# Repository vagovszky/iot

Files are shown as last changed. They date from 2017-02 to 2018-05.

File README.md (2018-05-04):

# IoT project
IoT project with usage of ESP8266 - [Wiki page](https://github.com/vagovszky/iot/wiki)

## Roadmapa - sketch

### Hardware - Hlavní modul

- [X] Návrh HW - schema (únor 2017)
- [X] Návrh HW - DPS (únor 2017)
- [X] Výroba DPS - Prototyp (únor 2017)
- [X] Osazení DPS (brezen 2017)
- [X] Celková kompletace modulu (brezen 2017)
- [X] Základní otestování (brezen 2017)

### Hardware - Přídavné moduly

- [X] Modul čidlo teploty
- [X] Modul I/O

## Výsledná sestava

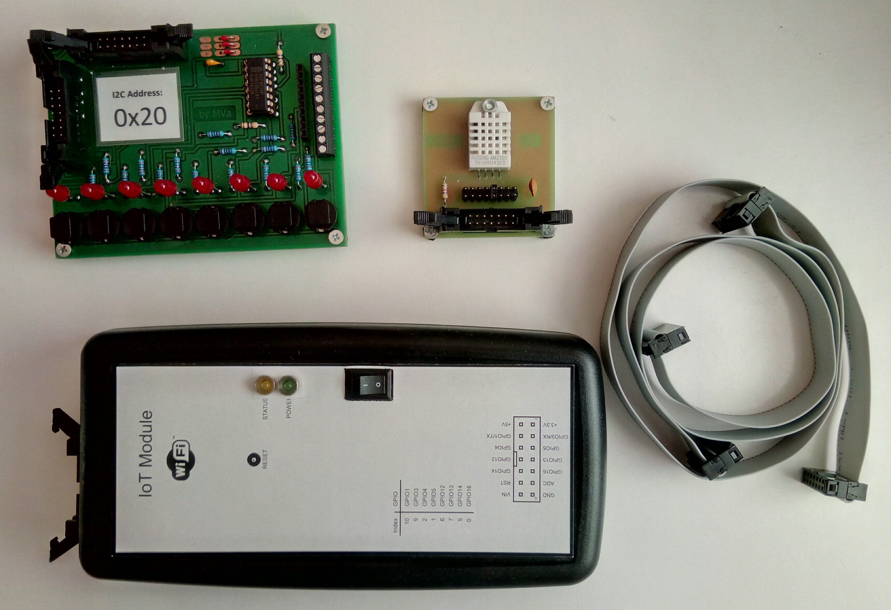
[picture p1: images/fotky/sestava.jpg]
Sestava


## Screenshot z webové aplikace k ovládání modulu

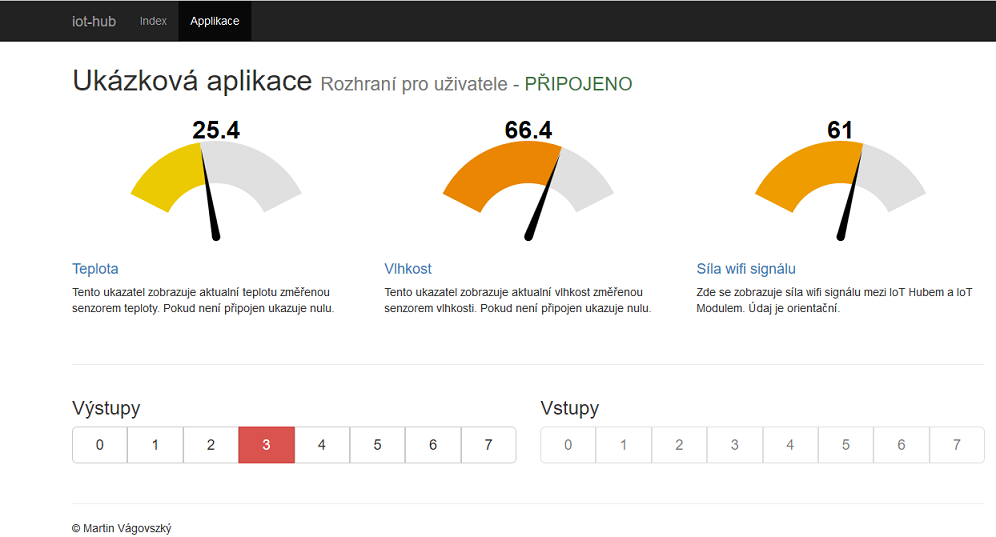
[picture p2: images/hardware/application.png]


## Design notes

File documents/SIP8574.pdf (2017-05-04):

# 8 I/O Port with LEDs and Relay

## September 29, 2009

## Contents

1 Introduction | 2
2 I2C Communications | 2
3 Operation | 2
4 Relay | 3
5 Misc Modifications | 4
6 Jumpers | 5
7 Edge Connector | 5
8 Drawings | 5
9 I2C Keyboard Drawings | 7
10 Revision History | 9

1

8 I/O Port with LEDs and Relay

## 1 Introduction

SIP8574 is a simple 8 bit I/O port module using the NXP (http://www.nxp.com) PCF8574 (http://www.nxp.com/pip/PCF8574_4.html)

This is the simplest I/O chip for I2C, with no input, output or data direction registers to configure. It has open drain outputs, which can be written or read.

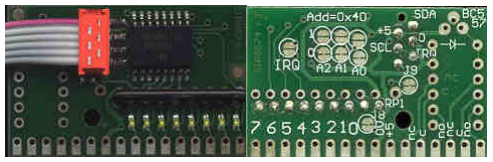
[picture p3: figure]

- 8 Open Drain I/O’s, 20mA
- Interrupt on pin change output
- TI 2nd source available

The SIP8574 module is included in the I2C Starter Kit.

I2C Keyboard

I2CKBD is a simple 8 buttons+leds pcb using the 8574.

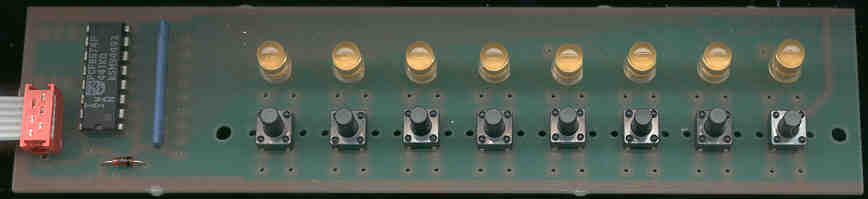
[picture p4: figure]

## 2 I2C Communications

The base address if PCF8574 is 0x40. 8 sub-addresses are available through J1-6.

There are no internal registers, all reads and write are direct to/from the port.

## 3 Operation

### 3.1 Input

Any pin you want to use as an input should be set HI.

S40 FF P //set all pins to be inputs

S41 01 P //read the input value

©Broadcast Equipment Ltd 2009 | www.i2cchip.com | SIP8574.lyx pg 2 of 9

8 I/O Port with LEDs and Relay

### 3.2 Output

The LED’s are ON when the outputs are LOW. So 00 will turn all LED’s on, FF will turn them off.

S40 00 P //all leds on
S40 FF P //all leds off
S40 FE P //relay only ON

You can write sequential bytes to the port to toggle the pins.

S40 FE FF FE FF P //toggle P0 twice

### 3.3 Paralleling Boards on Same Address

You might want to have a couple of boards in different spots, but you are only using a few pins. It might suit you to only have to write to a single location for both boards

You can actually parallel two boards without changing the address is you want. Just use different pins on each board, and leave the unused pins on each board open. This is possible because the I2C bus is open drain.

### 3.4 Reading Keyboards Switches

The I2CKBD has LED’s and buttons connected together.

To read the buttons the outputs are changed to all off - FF, then the port is read, then the LED state is restored.

So if LED state is F0, we can read the inputs, and set the leds like this:

S40 FF R01 W F0 P

ie Write FF, read 1 byte button values, write FF (led state).

### 3.5 Interrupt Pin

The IRQ pin is not connected by default. Bridge J7/IRQ to connect it to the bus.

## 4 Relay

You can order with a DPDT relay fitted. The PCB is labelled

- C - common
- NO - normally open
- NC normally closed.
©Broadcast Equipment Ltd 2009 | www.i2cchip.com | SIP8574.lyx pg 3 of 9

8 I/O Port with LEDs and Relay

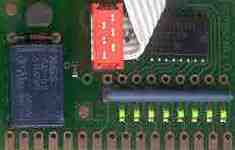
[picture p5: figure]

### 4.1 Relay Specifications

Spec | Value | Units
Type | NAIS TQ2-5V, DPDT
Max Voltage | 110 DC / 125 AC | V
Max Current | 1A | A
Nominal Switching | 30V 1A DC / 125VAC, 0.5A
Coil Current | 28 | mA

### 4.2 Adding the Relay

If not fitted you can add the relay yourself. You require:

- NAIS TQ2 type relay, 5V or equivalent,
- BC557 PNP 100mA transistor
- 1N4148, 1N914 or equivalent signal diode

### 4.3 Changing the Relay Port

By default the relay is connected to P0. To control it with another port, cut link J9. Use a wire to link the pad adjacent to R4, to the desired pad of RP2

[ADD photo]

### 4.4 Using the Relay Driver Without a Relay

The relay is high side driven by a PNP transistor. If you need a high current output, then you can fit Q1. Link across the relay pins to get the signal to the edge connector.

If you are driving an inductive load (eg external relay) be sure to fit D1.

## 5 Misc Modifications

### 5.1 Disable LED’s

To disable the LED’s cut J8.

You might want to do this to reduce current consumption, or if you want to drive the input from a source than cannot turn the LED on.

©Broadcast Equipment Ltd 2009 | www.i2cchip.com | SIP8574.lyx pg 4 of 9

8 I/O Port with LEDs and Relay

### 5.2 Adding Extra Pullup Resistors

The PCF8574 has built in weak pullups. If you want to increase the pullup current, fit RP2.

## 6 Jumpers

J# | Function | default
J1-6 | I2C Sub Address | joined to 0
J7 | IRQ | open
J8 | Cut to disable LED’s | closed
J9 | Cut to change Relay Port | closed

## 7 Edge Connector

Pin | Function
1 | normally open 1
2 | normally closed 1
3 | common 1
4 | normally open 2
5 | normally closed 2
6 | common 2
7 | +5
8 | GND
9 | IO 0
10 | IO 1
11 | IO 2
12 | IO 3
13 | IO 4
14 | IO 5
15 | IO 6
16 | IO 7

## 8 Drawings

### 8.1 Circuit Diagram

©Broadcast Equipment Ltd 2009 | www.i2cchip.com | SIP8574.lyx pg 5 of 9

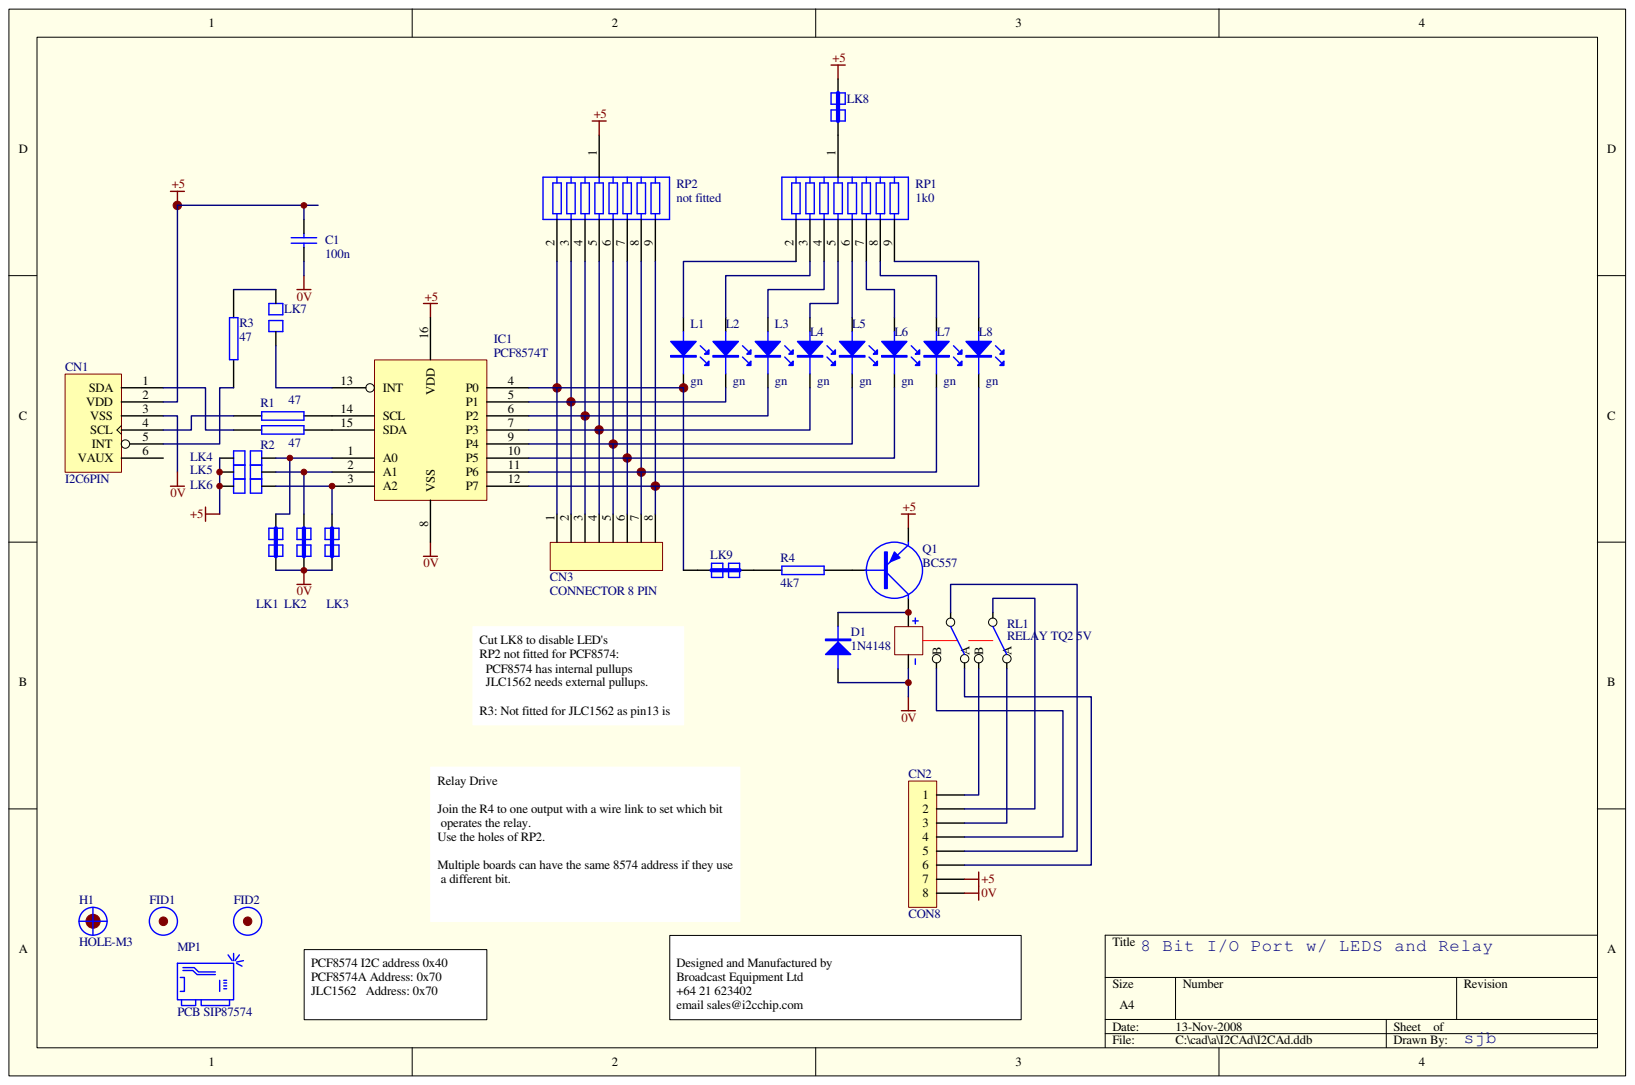
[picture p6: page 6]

Cut LK8 to disable LED's
RP2 not fitted for PCF8574:
PCF8574 has internal pullups
JLC1562 needs external pullups.

R3: Not fitted for JLC1562 as pin13 is

Join the R4 to one output with a wire link to set which bit
operates the relay.
Use the holes of RP2.

Multiple boards can have the same 8574 address if they use
a different bit.

Title
8 Bit I/O Port w/ LEDS and Relay

Designed and Manufactured by
Broadcast Equipment Ltd
email sales@i2cchip.com

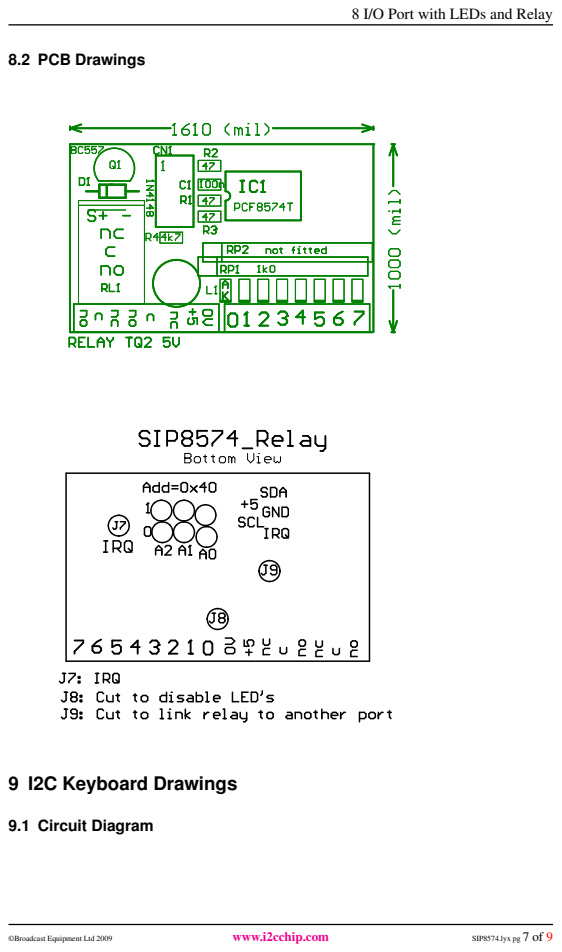
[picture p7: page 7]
8.2 PCB Drawings; 9 I2C Keyboard Drawings; 9.1 Circuit Diagram; ©Broadcast Equipment Ltd 2009; www.i2cchip.com; SIP8574.lyx pg 7 of 9

8 I/O Port with LEDs and Relay

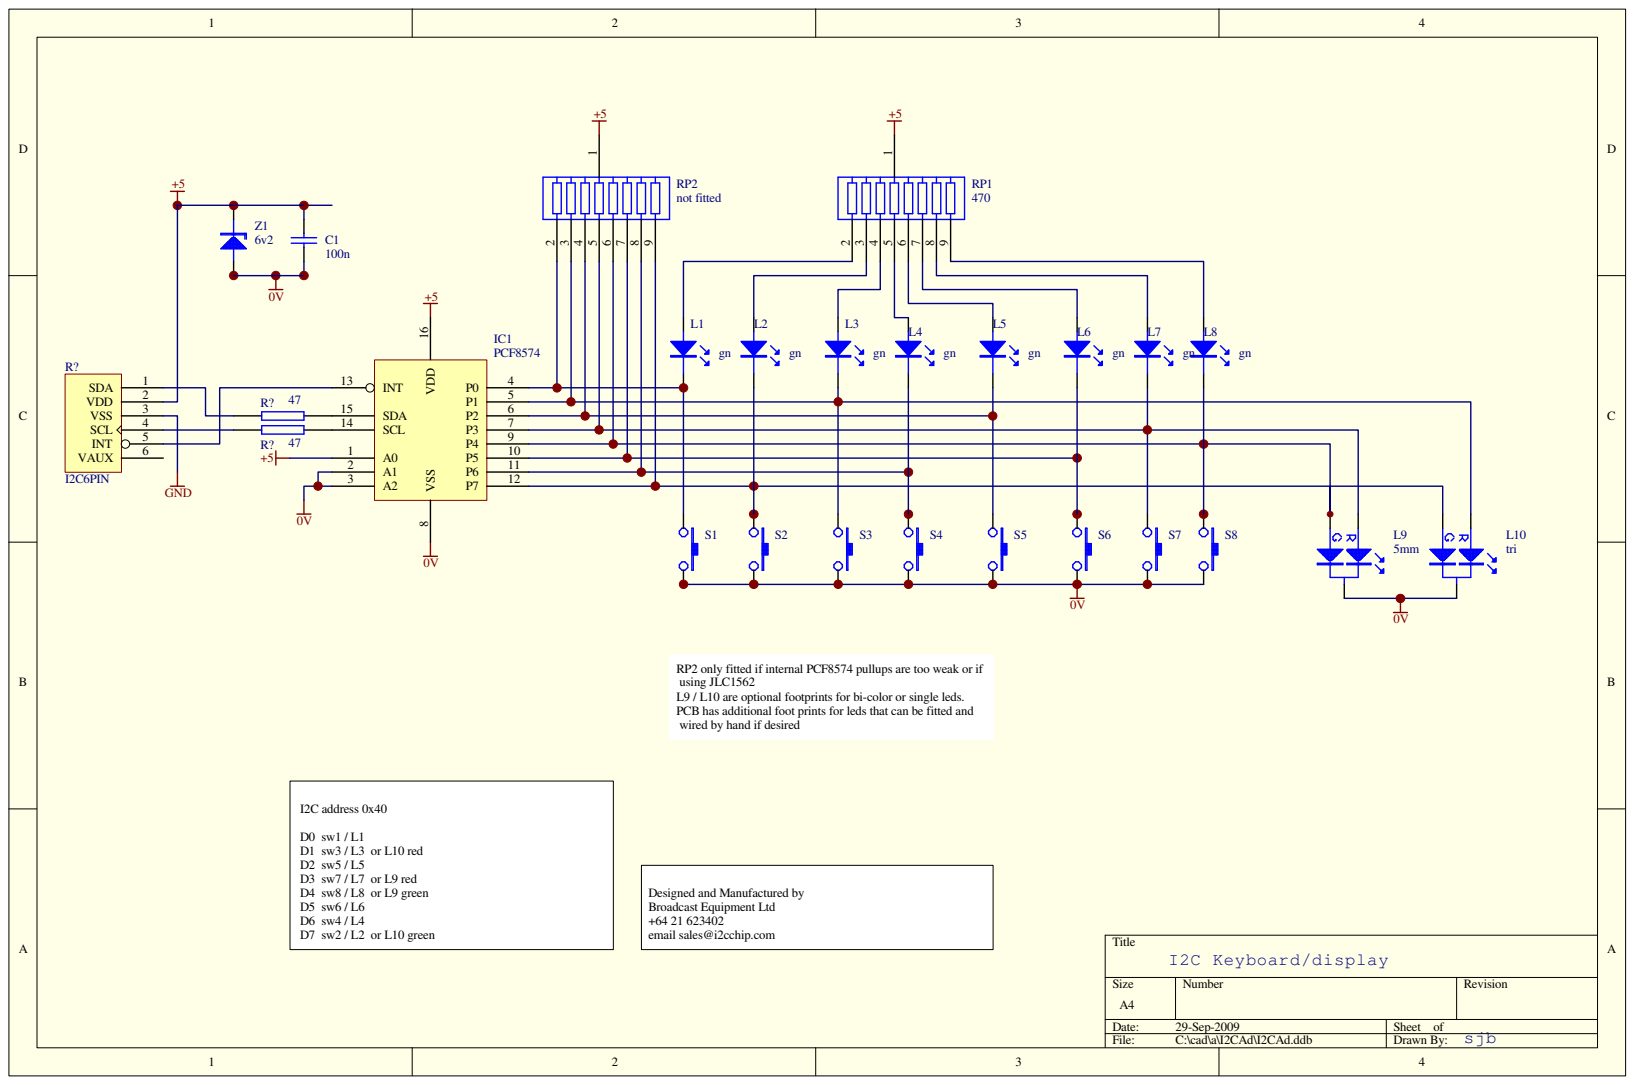
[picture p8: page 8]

RP2 only fitted if internal PCF8574 pullups are too weak or if
using JLC1562
L9 / L10 are optional footprints for bi-color or single leds.
PCB has additional foot prints for leds that can be fitted and
wired by hand if desired

Designed and Manufactured by
Broadcast Equipment Ltd
email sales@i2cchip.com

8 I/O Port with LEDs and Relay

## 10 Revision History

Date | Rev# | Changes
| 0 | pre-release
©Broadcast Equipment Ltd 2009 | www.i2cchip.com | SIP8574.lyx pg 9 of 9

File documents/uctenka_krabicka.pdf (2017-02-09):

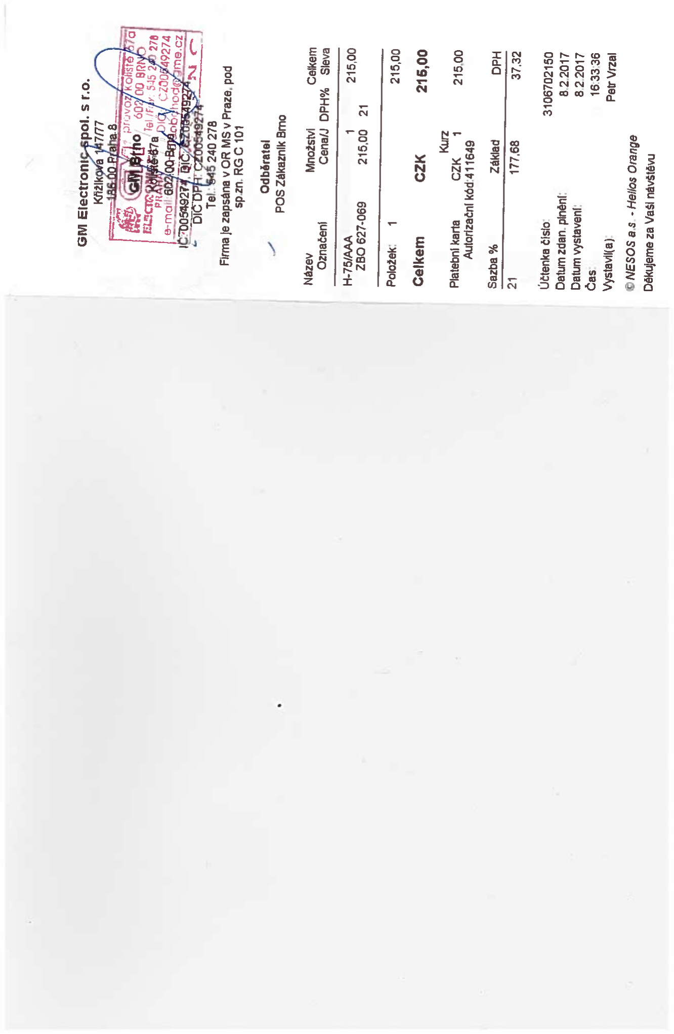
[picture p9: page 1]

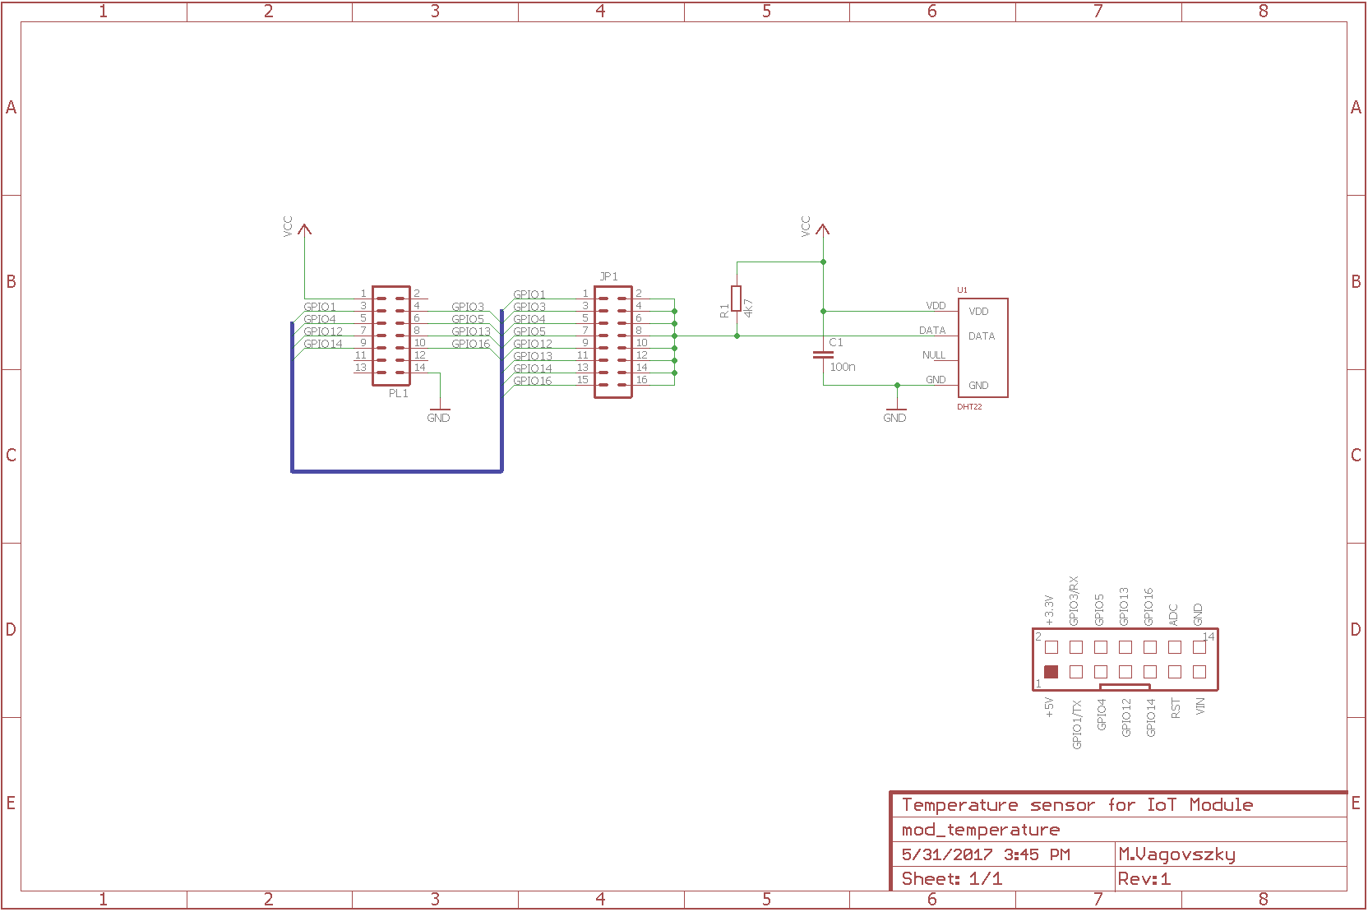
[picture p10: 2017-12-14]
images/hardware/mod_temperature_schema.png

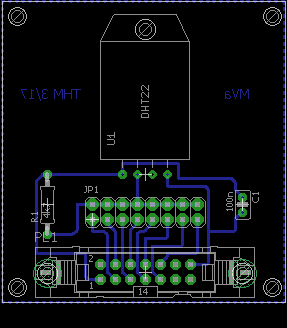
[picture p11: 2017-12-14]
images/hardware/mod_temperature_board.png

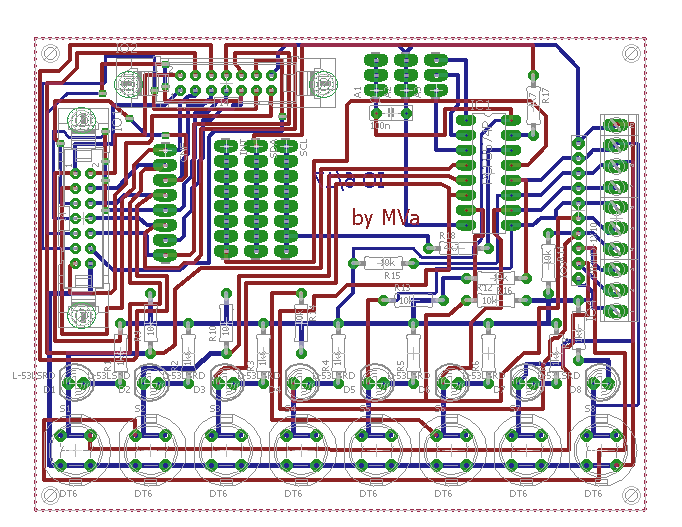
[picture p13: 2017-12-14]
images/hardware/mod_io_board_white.png

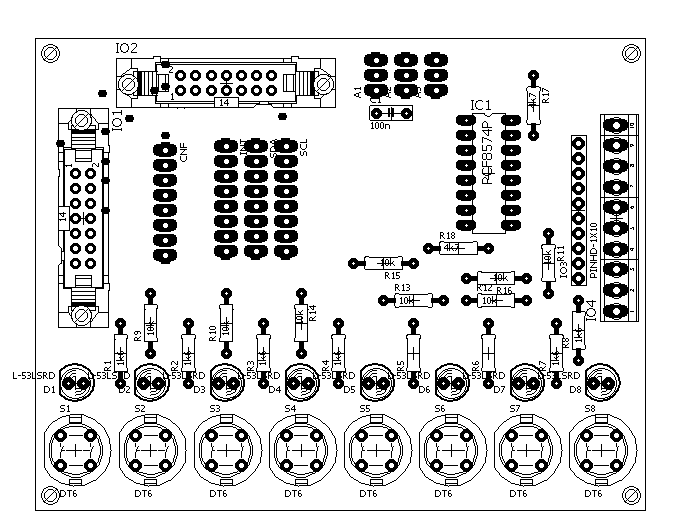
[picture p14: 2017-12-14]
images/hardware/mod_io_osaz.png

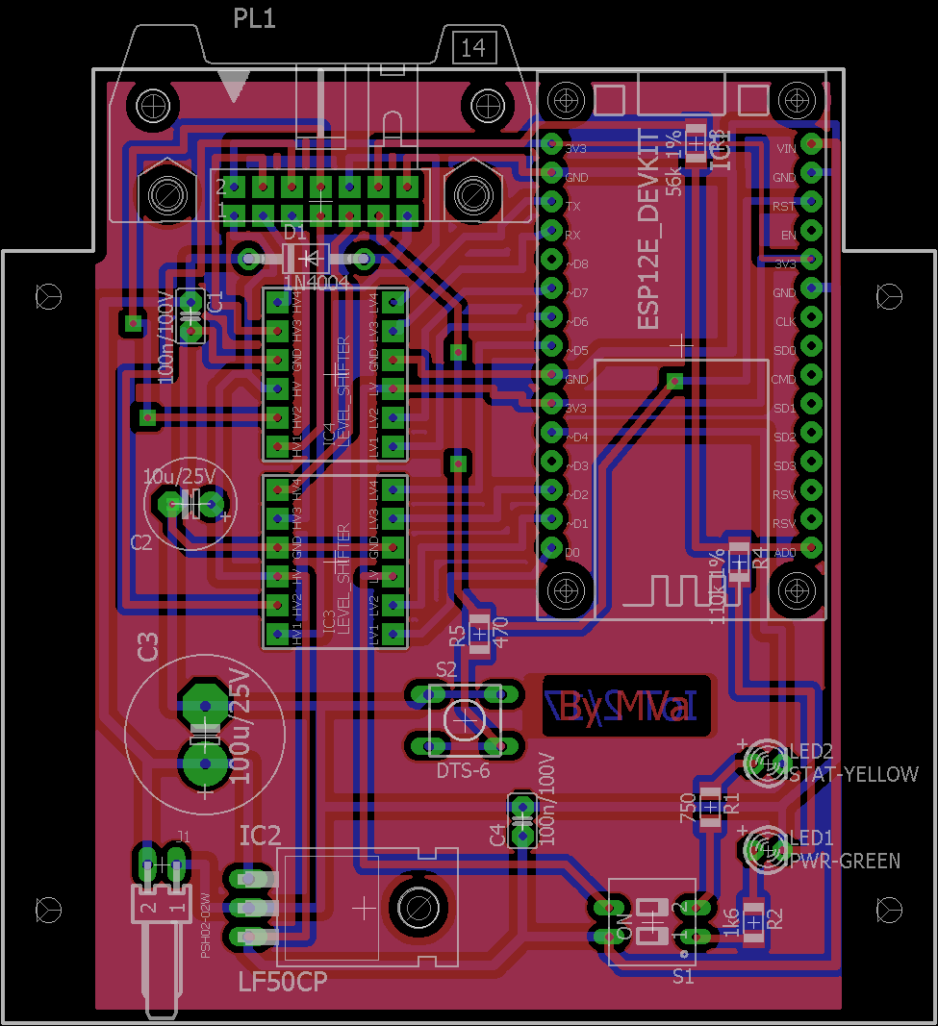
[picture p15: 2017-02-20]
images/hardware/board.png

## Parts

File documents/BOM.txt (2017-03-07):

C1,C4 KONDENZATOR 100n/100V - 2ks                      
C2    KONDENZATOR 10u/25V ELYT - 1ks                  
C3    KONDENZATOR 100u/25V ELYT - 1ks                 
D1    DIODA 1N4004 - 1ks                     
IC1   ESP12E_DEVKIT (EBAY) - 0ks       
IC2   REGULATOR LF50CP TO220H 5V LDO Regulator - 1ks          
IC3   LEVEL_SHIFTER Level shifter 5V <-> 3.3V (EBAY) - 0ks    
IC4   LEVEL_SHIFTER Level shifter 5V <-> 3.3V (EBAY) - 0ks   
J1    KONEKTOR PSH02-02W + OPACNÝ DÍL + PINY - 1ks                
LED1  LED 3MM Green BL-B2141-L (1,8V / 2mA) - 1ks                      
LED2  LED 3MM YELLOW HLMP-1719 (1,8V / 2mA) - 1ks                       
PL1   KONEKTOR PSL14W - 1ks                 
R1    REZISTOR 750 SMD 1206 - 2ks 
R2    REZISTOR 1k6 SMD 1206 - 2ks 
R3    REZISTOR 56k 1% SMD 1206 - 2ks 
R4    REZISTOR 110k 1% SMD 1206 - 2ks 
R5    REZISTOR 470 SMD 1206 - 2ks 
S1    SPÍNAC DO DPS DIP 02 RED/BLACK - 1ks          
S2    MIKROSPINAC DO DPS (asi TC-0111-T 13.5MM) - zmmerit delku hmatniku - 1ks
S3    POSUVNY SPINAC JEDNOPOLOVY CERNY DO PANELU - 1ks

Objímka pro led 3mm do panelu (reflektor / sokl) - 2ks
KONEKTOR PFL14 (NA KABEL) + TRMEN - 4ks
Podložky pod sroub M3 plastove
Distancni sloupek plastovy maly (5mm)

Krabicka H-75/4AA - 0ks
Plochý kabel - 14 žil - 1m

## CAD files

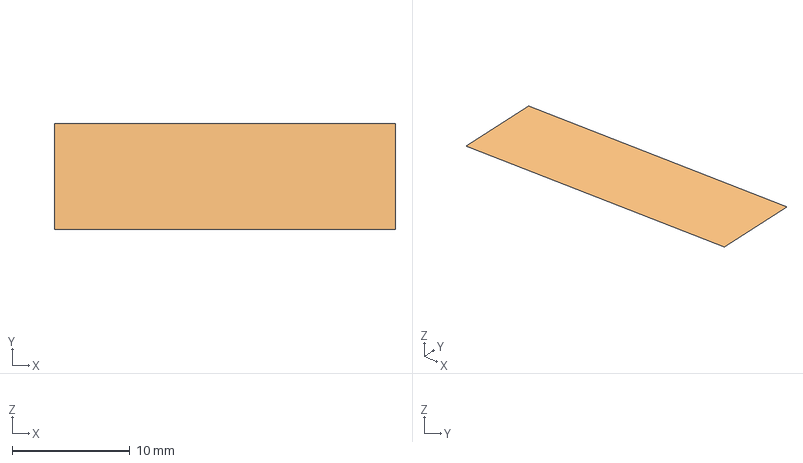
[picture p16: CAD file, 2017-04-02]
freecad/IoT_Front_Label.fcstd
29.0 x 9.00 x 0 mm
Pins
Closure
Locker

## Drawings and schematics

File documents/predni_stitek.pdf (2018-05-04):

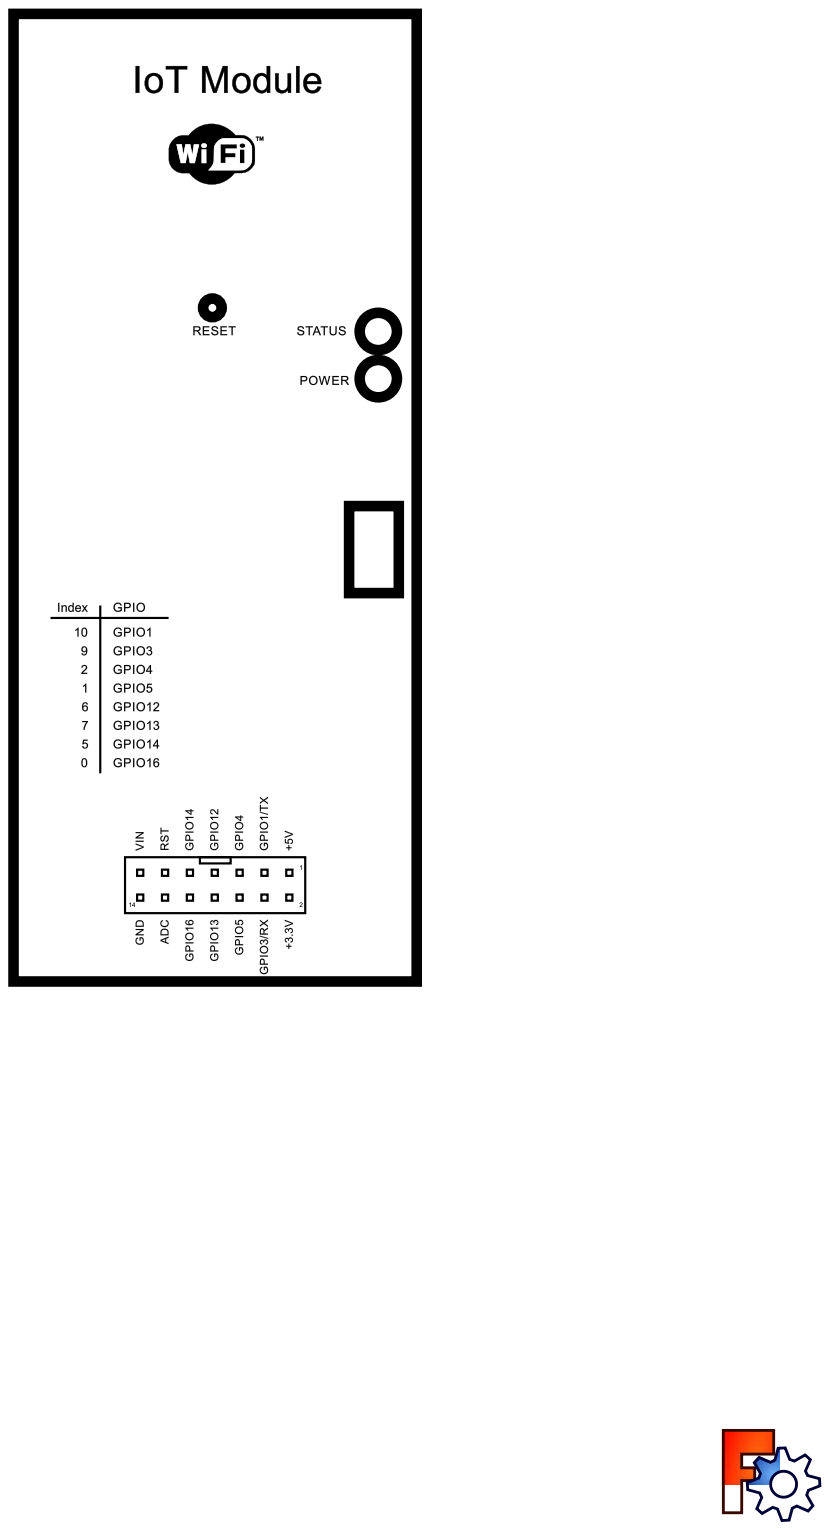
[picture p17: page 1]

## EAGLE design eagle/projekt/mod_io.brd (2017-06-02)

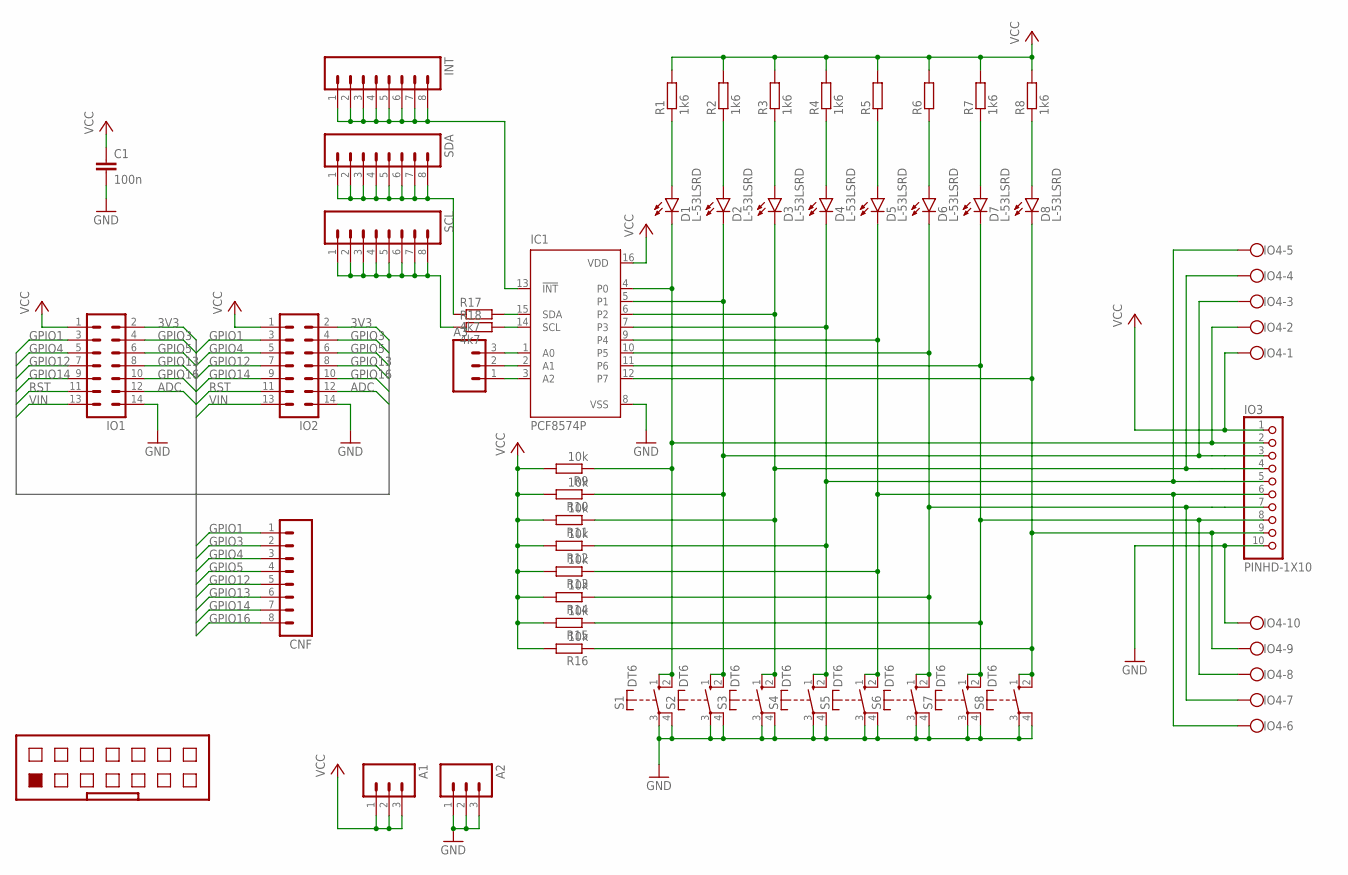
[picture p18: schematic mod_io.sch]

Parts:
A1, A2, A3: M03LONGPADS; 1X03_LONGPADS
C1: 100n; C050-025X075
CNF: M08LONGPADS; 1X08_LONGPADS
D1, D2, D3, D4, D5, D6, D7, D8: L-53LSRD; LED5MM
IC1: PCF8574P; DIL16
INT: M08LONGPADS; 1X08_LONGPADS
IO1, IO2: 14V
IO3: PINHD-1X10; 1X10-BIG
IO4: AK550/10
R1, R2, R3, R4, R7, R8: 1k6; 0207/10
R5, R6: R-EU_0207/10; 0207/10
R9, R10, R11, R12, R13, R14, R15, R16: 10k; 0207/10
R17, R18: 4k7; 0207/10
S1, S2, S3, S4, S5, S6, S7, S8: DT6
SCL: M08LONGPADS; 1X08_LONGPADS
SDA: M08LONGPADS; 1X08_LONGPADS

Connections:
3V3: IO1.2, IO2.2
ADC: IO1.12, IO2.12
GND: A2.1, A2.2, A2.3, C1.2, IC1.8 (VSS), IO1.14, IO2.14, IO3.10, IO4.10, S1.3, S1.4, S2.3, S2.4, S3.3, S3.4, S4.3, S4.4, S5.3, S5.4, S6.3, S6.4, S7.3, S7.4, S8.3, S8.4
GPIO1: CNF.1, IO1.3, IO2.3
GPIO3: CNF.2, IO1.4, IO2.4
GPIO4: CNF.3, IO1.5, IO2.5
GPIO5: CNF.4, IO1.6, IO2.6
GPIO12: CNF.5, IO1.7, IO2.7
GPIO13: CNF.6, IO1.8, IO2.8
GPIO14: CNF.7, IO1.9, IO2.9
GPIO16: CNF.8, IO1.10, IO2.10
unnamed: D5.K (C), IC1.9 (P4), IO3.6, IO4.6, R13.1, S5.1 (S), S5.2 (S)
unnamed: D6.K (C), IC1.10 (P5), IO3.7, IO4.7, R14.1, S6.1 (S), S6.2 (S)
unnamed: D1.K (C), IC1.4 (P0), IO3.2, IO4.2, R9.1, S1.1 (S), S1.2 (S)
unnamed: D2.K (C), IC1.5 (P1), IO3.3, IO4.3, R10.1, S2.1 (S), S2.2 (S)
unnamed: D3.K (C), IC1.6 (P2), IO3.4, IO4.4, R11.1, S3.1 (S), S3.2 (S)
unnamed: D4.K (C), IC1.7 (P3), IO3.5, IO4.5, R12.1, S4.1 (S), S4.2 (S)
unnamed: D7.K (C), IC1.11 (P6), IO3.8, IO4.8, R15.1, S7.1 (S), S7.2 (S)
unnamed: D8.K (C), IC1.12 (P7), IO3.9, IO4.9, R16.1, S8.1 (S), S8.2 (S)
unnamed: D6.A, R6.1
unnamed: D5.A, R5.1
unnamed: D7.A, R7.1
unnamed: D8.A, R8.1
unnamed: D1.A, R1.1
unnamed: D2.A, R2.1
unnamed: D3.A, R3.1
unnamed: D4.A, R4.1
unnamed: IC1.13 (!INT), INT.1, INT.2, INT.3, INT.4, INT.5, INT.6, INT.7, INT.8
unnamed: A3.3, IC1.1 (A0)
unnamed: A3.2, IC1.2 (A1)
unnamed: A3.1, IC1.3 (A2)
unnamed: IC1.15 (SDA), R17.2
unnamed: IC1.14 (SCL), R18.2
unnamed: R17.1, SDA.1, SDA.2, SDA.3, SDA.4, SDA.5, SDA.6, SDA.7, SDA.8
unnamed: R18.1, SCL.1, SCL.2, SCL.3, SCL.4, SCL.5, SCL.6, SCL.7, SCL.8
RST: IO1.11, IO2.11
VCC: A1.1, A1.2, A1.3, C1.1, IC1.16 (VDD), IO1.1, IO2.1, IO3.1, IO4.1, R1.2, R2.2, R3.2, R4.2, R5.2, R6.2, R7.2, R8.2, R9.2, R10.2, R11.2, R12.2, R13.2, R14.2, R15.2, R16.2
VIN: IO1.13, IO2.13

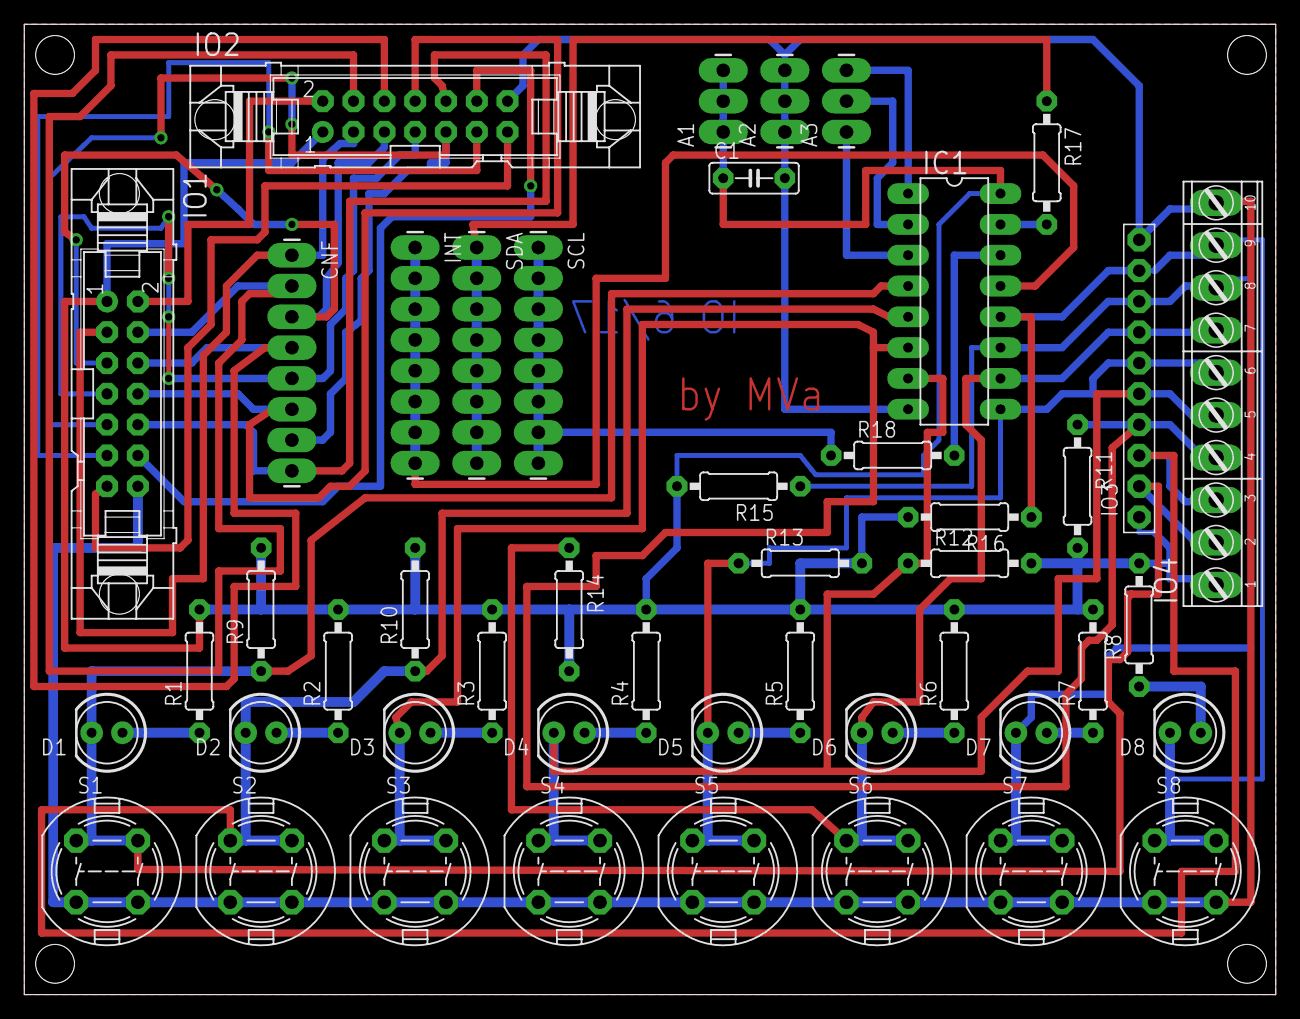
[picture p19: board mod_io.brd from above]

Board: 2 copper layers, 103.2 x 80.0 mm, 47 parts (0 on the bottom side), 38 nets.

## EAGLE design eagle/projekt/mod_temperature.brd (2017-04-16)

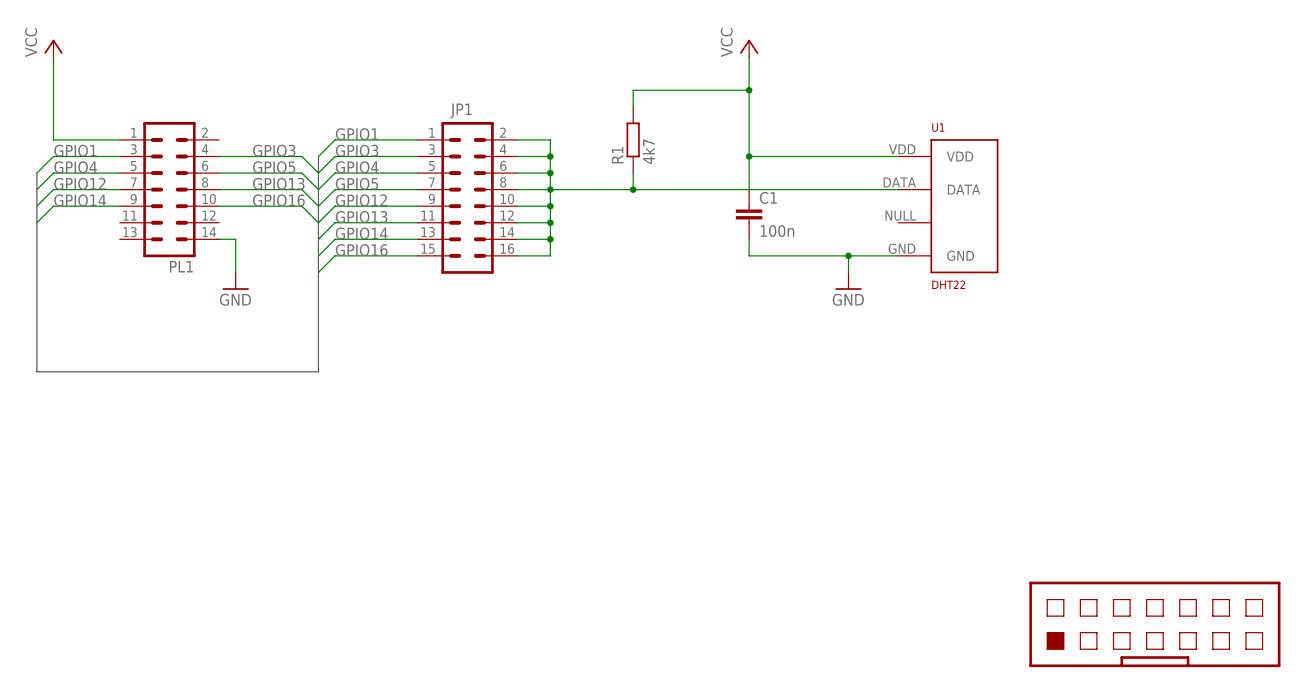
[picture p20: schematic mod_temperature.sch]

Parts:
C1: 100n; C025-025X050
JP1: M08X2; 2X8
PL1: 14V
R1: 4k7; 0207/10
U1: DHT22; RHT03_DHT-22/RA

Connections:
GND: C1.2, PL1.14, U1.GND
GPIO1: JP1.1, PL1.3
GPIO3: JP1.3, PL1.4
GPIO4: JP1.5, PL1.5
GPIO5: JP1.7, PL1.6
GPIO12: JP1.9, PL1.7
GPIO13: JP1.11, PL1.8
GPIO14: JP1.13, PL1.9
GPIO16: JP1.15, PL1.10
unnamed: JP1.2, JP1.4, JP1.6, JP1.8, JP1.10, JP1.12, JP1.14, JP1.16, R1.1, U1.DATA
VCC: C1.1, PL1.1, R1.2, U1.VDD

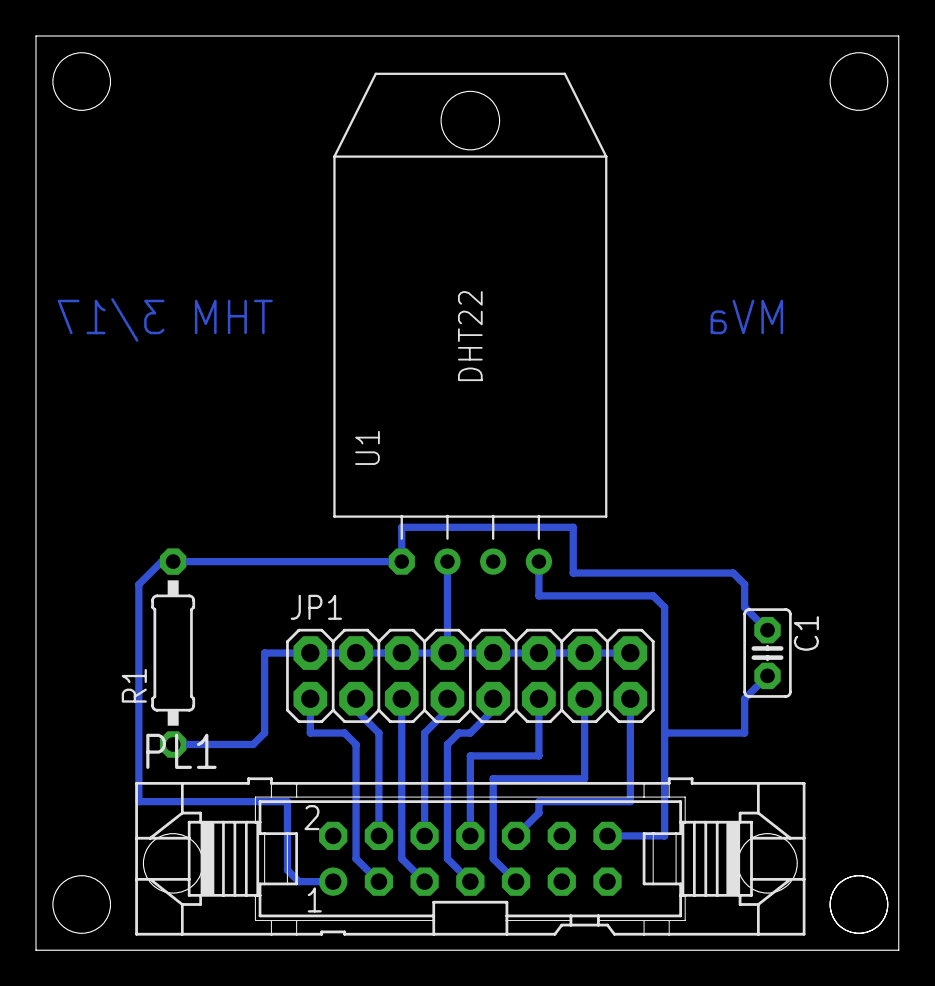
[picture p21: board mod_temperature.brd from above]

Board: 2 copper layers, 47.9 x 50.8 mm, 5 parts (0 on the bottom side), 11 nets.

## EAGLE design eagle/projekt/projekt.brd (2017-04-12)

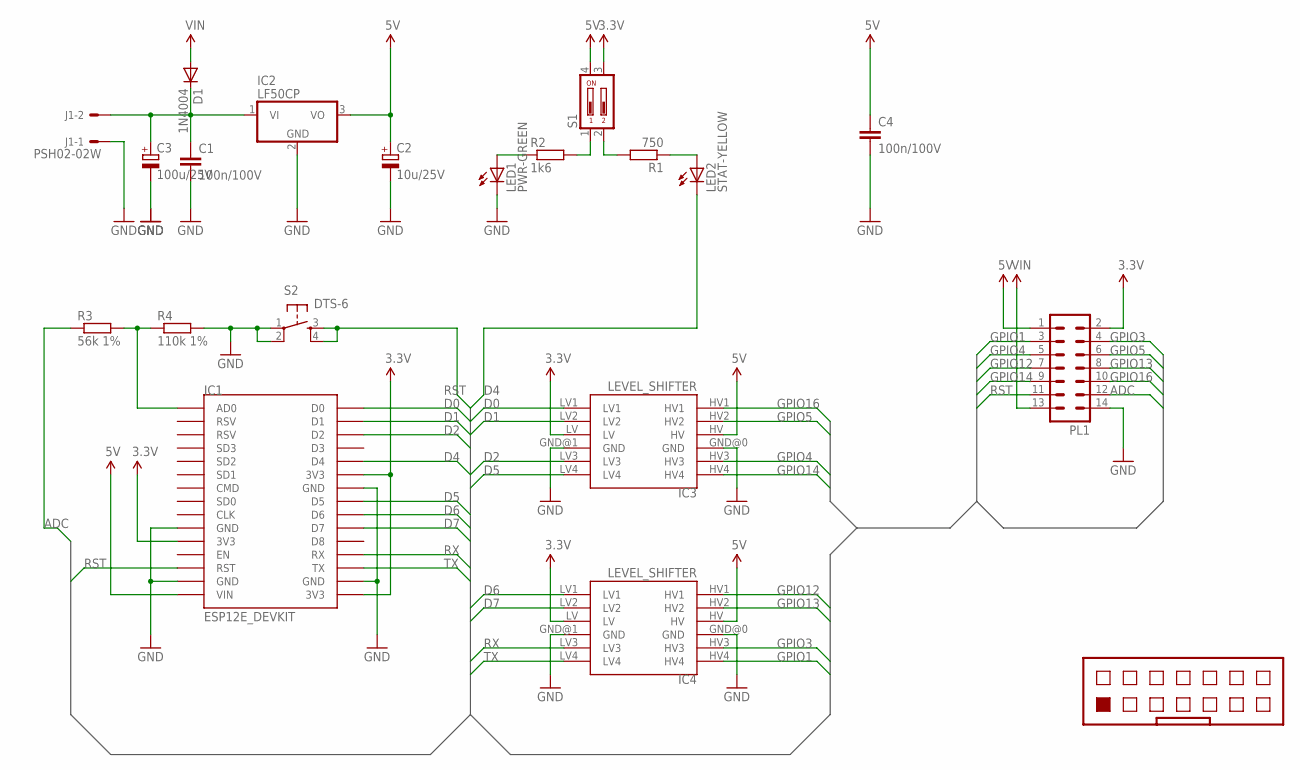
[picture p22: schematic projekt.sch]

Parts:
C1, C4: 100n/100V; C025-025X050
C2: 10u/25V; E3,5-8
C3: 100u/25V; E5-13
D1: 1N4004; DO41-10
IC1: ESP12E_DEVKIT
IC2: LF50CP; TO220H
IC3, IC4: LEVEL_SHIFTER
J1: PSH02-02W; 7395-02
LED1: PWR-GREEN; LED3MM
LED2: STAT-YELLOW; LED3MM
PL1: 14H
R1: 750; R1206
R2: 1k6; R1206
R3: 56k 1%; R1206
R4: 110k 1%; R1206
S1: DIP02YL
S2: DTS-6

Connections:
3.3V: IC1.3V3@0 (3V3), IC1.3V3@1 (3V3), IC1.3V3@2 (3V3), IC3.LV, IC4.LV, PL1.2, S1.3
5V: C2.+, C4.1, IC1.VIN, IC2.3 (VO), IC3.HV, IC4.HV, PL1.1, S1.4
ADC: PL1.12, R3.1
D0: IC1.D0, IC3.LV1
D1: IC1.D1, IC3.LV2
D2: IC1.D2, IC3.LV3
D4: IC1.D4, LED2.K (C)
D5: IC1.D5, IC3.LV4
D6: IC1.D6, IC4.LV1
D7: IC1.D7, IC4.LV2
GND: C1.2, C2.-, C3.-, C4.2, IC1.GND@0 (GND), IC1.GND@1 (GND), IC1.GND@2 (GND), IC1.GND@3 (GND), IC2.2 (GND), IC3.GND@0 (GND), IC3.GND@1 (GND), IC4.GND@0 (GND), IC4.GND@1 (GND), J1.1, LED1.K (C), PL1.14, R4.2, S2.1, S2.2
GPIO1: IC4.HV4, PL1.3
GPIO3: IC4.HV3, PL1.4
GPIO4: IC3.HV3, PL1.5
GPIO5: IC3.HV2, PL1.6
GPIO12: IC4.HV1, PL1.7
GPIO13: IC4.HV2, PL1.8
GPIO14: IC3.HV4, PL1.9
GPIO16: IC3.HV1, PL1.10
unnamed: IC1.AD0, R3.2, R4.1
unnamed: LED1.A, R2.1
unnamed: R2.2, S1.1
unnamed: R1.2, S1.2
unnamed: LED2.A, R1.1
unnamed: C1.1, C3.+, D1.C, IC2.1 (VI), J1.2
RST: IC1.RST, PL1.11, S2.3, S2.4
RX: IC1.RX, IC4.LV3
TX: IC1.TX, IC4.LV4
VIN: D1.A, PL1.13

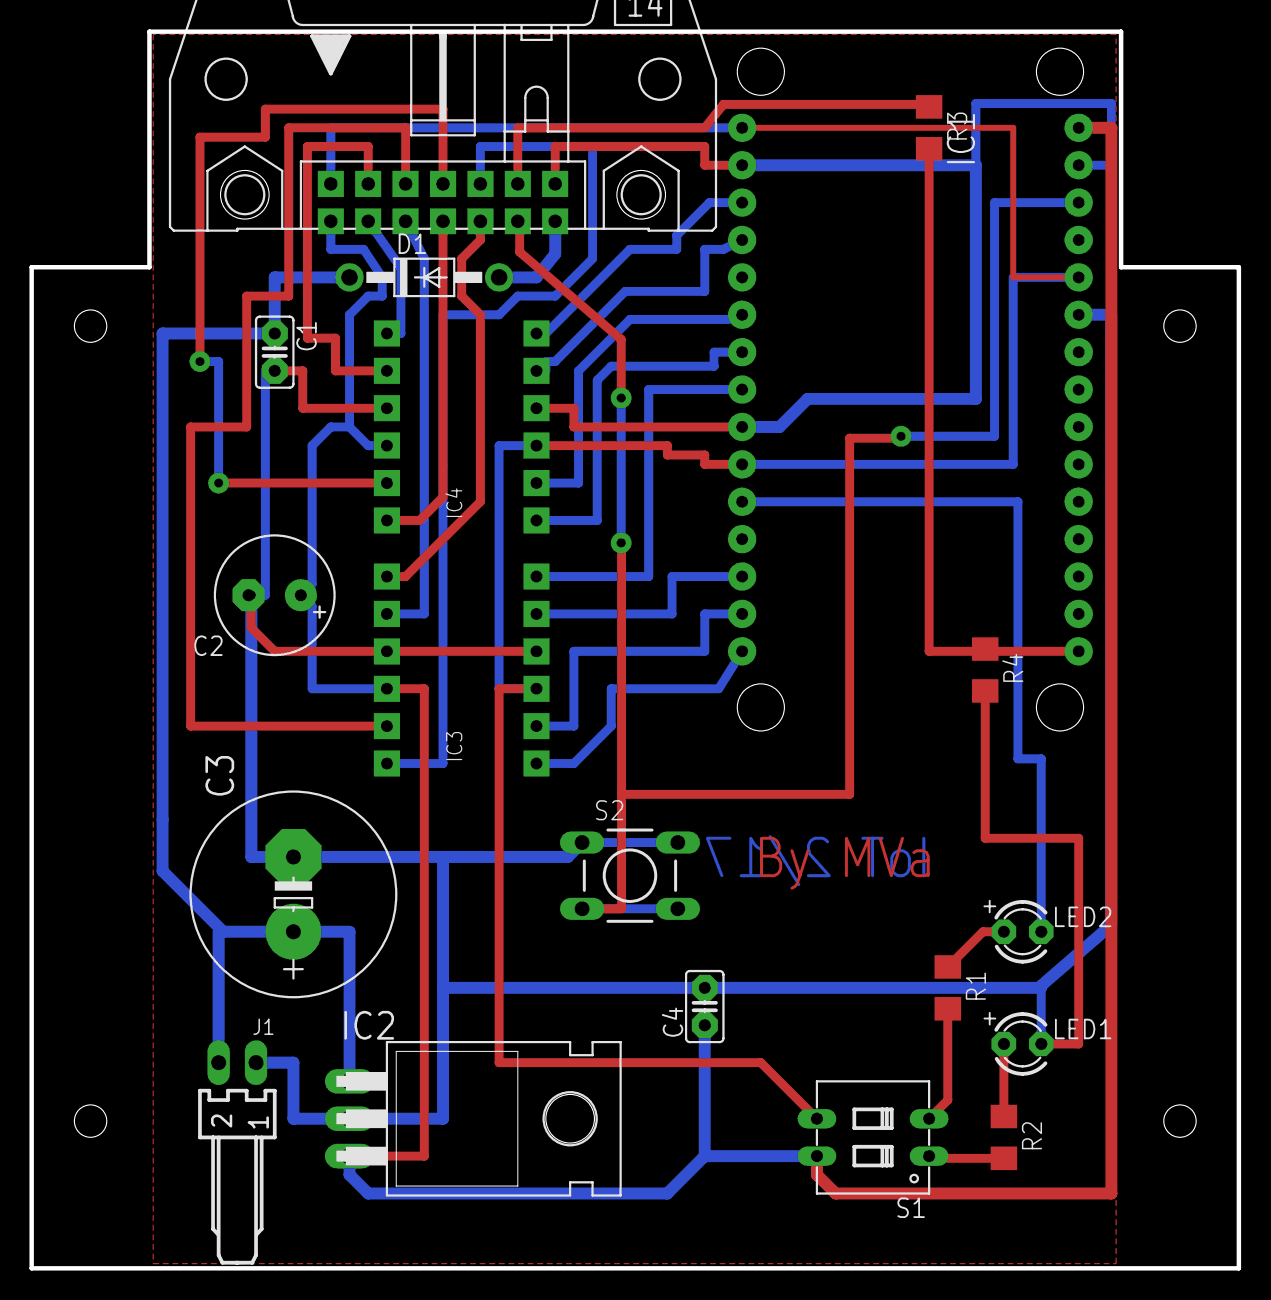
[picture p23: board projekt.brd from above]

Board: 2 copper layers, 82.0 x 84.0 mm, 19 parts (0 on the bottom side), 29 nets.

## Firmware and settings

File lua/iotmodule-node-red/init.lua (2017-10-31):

pcf8574=require("pcf8574")

MQTT_HOST="192.168.0.1"
MQTT_CLIENT_ID="IOT-Module"
MQTT_USER_NAME=""
MQTT_PASSWORD=""

WIFICFG={}
WIFICFG.ssid="iot-hub"
WIFICFG.pwd=""

MQTT_STATUS_LED = 4
DHT_DATA_PIN = 6
INT_PIN = 5
SCL_PIN = 2
SDA_PIN = 1

register = 255
dhtEnabled = false
pcf8574enabled = false

print("IOT Module initializing...")
tmr.create():alarm(2000, tmr.ALARM_SINGLE, function() setup() end)

function setup()
    -- Pin setup
    print("IOT Module entering setup...")
    gpio.mode(MQTT_STATUS_LED, gpio.OUTPUT)
    gpio.write(MQTT_STATUS_LED, gpio.HIGH)
    gpio.mode(INT_PIN,gpio.INT,gpio.PULLUP)
    i2c.setup(0, SDA_PIN, SCL_PIN, i2c.SLOW)
    -- MQTT setup
    m = mqtt.Client(MQTT_CLIENT_ID,120,MQTT_USER_NAME,MQTT_PASSWORD)
    -- Check if modules are available
    status, temp, humi, temp_dec, humi_dec = dht.read(DHT_DATA_PIN)
    numB = pcf8574.write(register)
    if numB > 0 then 
        pcf8574enabled = true 
        print("PCF8574 connected...")
    end
    if status == dht.OK then 
        dhtEnabled = true 
        print("DHT module connected...")
    end
    -- Handle incomming messages (pin sets)
    m:on("message", function(m,topic,data) 
        gpio.write(MQTT_STATUS_LED, gpio.HIGH)
        print(topic .. " " .. data)
        if pcf8574enabled and topic == 'iotmodule/output' then
            local dataJson = sjson.decode(data)
            if dataJson.bit~=nil and dataJson.state~=nil then
                id = tonumber(dataJson.bit)
                if tonumber(dataJson.state) == 1 then
                    register = bit.clear(register, id)
                elseif tonumber(dataJson.state) == 0 then
                    register = bit.set(register, id)
                end
                pcf8574.write(register)
            end 
        end
        tmr.create():alarm(200, tmr.ALARM_SINGLE, function() gpio.write(MQTT_STATUS_LED, gpio.LOW) end)
    end)
    -- Wifi starting
    print("Starting wifi...")
    wifi.setmode(wifi.STATION)
    wifi.setphymode(wifi.PHYMODE_N)
    wifi.sta.config(WIFICFG)
    wifi.sta.connect()
    local wifiT = tmr.create()
    wifiT:alarm(1000, tmr.ALARM_AUTO, function()
        print("Connecting to wifi...")
        if wifi.sta.status() == 5 then
            print("Connected to wifi...")
            tmr.unregister(wifiT)
            main()
        end
    end)
end

function main()
    m:connect(MQTT_HOST, 1883, 0, 1, function(client)
        print("Connected to MQTT...")
        gpio.write(MQTT_STATUS_LED, gpio.LOW)
        -- MQTT subscribe
        if pcf8574enabled then
            print("Subscribing topics iotmodule/output")
            m:subscribe('iotmodule/output', 0)
        end
        -- Handle button press
        gpio.trig(INT_PIN, "down", function(level, when) 
            local port = string.byte(pcf8574.read())
            local res = {}
            if port ~= nil then
                if port ~= register then
                    local pxor = bit.bxor(port, register)
                    res.bit = 0
                    for i = 0,7 do
                        if (2 ^ i) == pxor then
                            res.bit = i
                            break
                        end
                    end
                    gpio.write(MQTT_STATUS_LED, gpio.HIGH)
                    m:publish('iotmodule/input', sjson.encode(res) ,0,0, function(client)
                        print('iotmodule/input '..sjson.encode(res)) 
                    end)
                    tmr.create():alarm(200, tmr.ALARM_SINGLE, function() gpio.write(MQTT_STATUS_LED, gpio.LOW) end)
                end
            end
        end)
        -- Main loop
        tmr.create():alarm(10000, tmr.ALARM_AUTO, function() 
            local sensorData = {}
            sensorData.temperature = 0
            sensorData.humidity = 0
            sensorData.wifi = 0
            sensorData.register = 255
            if dhtEnabled then
                status, temp, humi, temp_dec, humi_dec = dht.read(DHT_DATA_PIN)
                if status == dht.OK then
                    sensorData.temperature = string.format('%d.%01d', math.floor(temp), temp_dec)
                    sensorData.humidity = string.format('%d.%01d', math.floor(humi), humi_dec)
                end
            end
            if pcf8574enabled then
                sensorData.register = register
            end
            sensorData.wifi = wifi.sta.getrssi()
            gpio.write(MQTT_STATUS_LED, gpio.HIGH)
            m:publish('iotmodule/sensors', sjson.encode(sensorData) ,0,0, function(client)
                print('iotmodule/sensors '..sjson.encode(sensorData))
            end)
            tmr.create():alarm(200, tmr.ALARM_SINGLE, function() gpio.write(MQTT_STATUS_LED, gpio.LOW) end)
        end)
    end)
end

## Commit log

2017-02-09 Aktualizace obrazku, BOM, uctenka krabicka
2017-02-09 Aktualizace BOM, datasheet LDO reg.
2017-02-10 Eagle - schema, knihovny
    [schema.sch]
2017-02-17 Podklady pro vyrobu DPS
    [projekt.brd, projekt.sch]
2017-02-20 Board - podklady
    [projekt.brd]
2017-03-12 Nakres predniho panelu
    [IoT_Front_Label.fcstd]
2017-03-22 Osazena deska + label
    [IoT_Front_Label.fcstd]
2017-04-12 Schema - Rev 2
    [projekt.brd, projekt.sch]
2017-04-12 Mod temp
    [mod_temperature.sch]
2017-04-16 Cidlo teploty
    [mod_io.sch, mod_temperature.brd, mod_temperature.sch]
2017-05-31 Update schematu
    [mod_io.sch]
2017-06-01 Deska mod IO
    [mod_io.brd]
2017-06-01 Deska, modul IO
    [mod_io.brd]
2017-06-02 Modul IO deska podklady
    [mod_io.brd]
2017-10-11 Zaukrouhleni teploty a vlhkosti na 1 des. misto
2017-10-31 Bliknuti ledkou pri prijeti nebo odeslani zpravy

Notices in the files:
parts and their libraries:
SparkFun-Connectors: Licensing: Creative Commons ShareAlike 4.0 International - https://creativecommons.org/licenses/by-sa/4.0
